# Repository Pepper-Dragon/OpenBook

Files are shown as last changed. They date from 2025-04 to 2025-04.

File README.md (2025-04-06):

# OpenBook
Proiect TSC - Diaconu Andrei 331CB

## Block Diagram

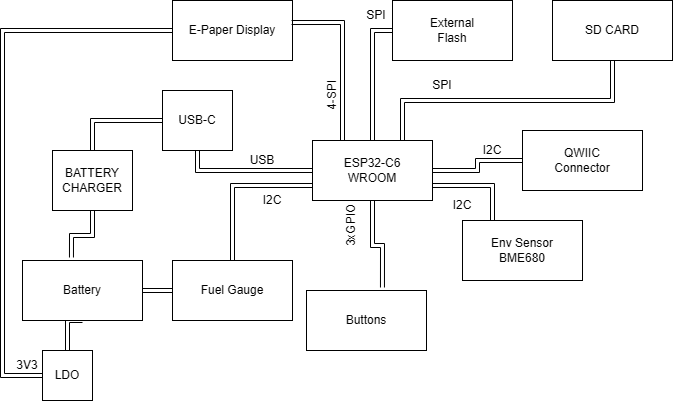
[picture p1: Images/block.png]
block


## Components

- **Microcontroller:** ESP32-C6 with integrated Wi-Fi 6 and Bluetooth 5 — responsible for core processing, communication, and power management.
- **Display:** 800×480 resolution e-Paper (e-Ink) display interfaced via SPI — ideal for low-power, high-visibility content rendering.
- **Sensors:** BME688 environmental sensor (temperature, humidity, pressure, air quality) connected through I2C.
- **Power Supply:** 2500mAh LiPo battery with USB-C charging and integrated fuel gauge for real-time battery monitoring.
- **Storage:** MicroSD card slot for storing e-books and other resources, communicating via SPI.
- **Real-Time Clock:** DS3231 RTC module with battery backup for accurate timekeeping even during power loss.
- **User Inputs:** 3 buttons (connected via GPIO) for navigation and control.
- **Expansion Options:** QWIIC/Stemma QT connector for easy integration of additional sensors or modules.

## Bill Of Materials

| name 	| value 	| description 	| quantity 	| link 	| datasheet 	|
|:---:	|:---:	|---	|:---:	|:---:	|---	|
| LED1 	| - 	| LED 	| 1 	| [link](https://www.niden.ro/led-uri-smd/4560-led-smd-0603-alb-rece.html) 	| [link](https://www.mouser.com/datasheet/2/423/LSM0603472V_(1)-1379786.pdf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)	|
| C18 	| 0.1uF/50V 	| CAPACITOR, European symbol 	| 1 	| [link](https://ro.mouser.com/ProductDetail/KEMET/C0402C104K4RAC7411?qs=GedzDrHbfJPMv36lRRfk4g%3D%3D) 	| [link](https://ro.mouser.com/datasheet/2/447/KEM_C1002_X7R_SMD-3316098.pdf) 	|
| R5 	| 0.47 	| RESISTOR, European symbol 	| 1 	| [link](https://ro.mouser.com/ProductDetail/ROHM-Semiconductor/SFR01MZPJ471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) 	| [link](https://fscdn.rohm.com/en/products/databook/datasheet/passive/resistor/chip_resistor/sfr-e.pdf) 	|
| R1 	| 100K 	| RESISTOR, European symbol 	| 1 	| [link](https://ro.mouser.com/ProductDetail/Bourns/CR0402-FX-1003GLF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) 	| [link](https://ro.mouser.com/datasheet/2/54/cr-1858361.pdf) 	|
| C1, C5, C21, C22, C23, C25, C26, C27 	| 100nF 	| CAPACITOR, European symbol 	| 8 	| [link](https://ro.mouser.com/ProductDetail/KEMET/C0402C104K4RAC7411?qs=GedzDrHbfJPMv36lRRfk4g%3D%3D) 	| [link](https://ro.mouser.com/datasheet/2/447/KEM_C1002_X7R_SMD-3316098.pdf) 	|
| C2 	| 100uF 	| POLARIZED CAPACITOR, European symbol 	| 1 	| [link](https://ro.mouser.com/ProductDetail/KEMET/T491B107M006AT?qs=U312oeP%2FpiHOgyk6KO2m0g%3D%3D) 	| [link](https://ro.mouser.com/datasheet/2/447/KEM_T2005_T491-3316937.pdf) 	|
| R18 	| 10K 	| RESISTOR, European symbol 	| 1 	| [link](https://ro.mouser.com/ProductDetail/Vishay-Dale/CRCW040210K0FKEDC?qs=E3Y5ESvWgWPiNLcGzwCGPg%3D%3D) 	| [link](https://www.vishay.com/docs/28773/crcwce3.pdf) 	|
| R6, R10, R11, R12, R13, R14, R15, R16, R19, R20, R21, R22, R23, R24, R25 	| 10k 	| RESISTOR, European symbol 	| 15 	| [link](https://ro.mouser.com/ProductDetail/Vishay-Dale/CRCW040210K0FKEDC?qs=E3Y5ESvWgWPiNLcGzwCGPg%3D%3D) 	| [link](https://www.vishay.com/docs/28773/crcwce3.pdf) 	|
| C7 	| 10uF 	| CAPACITOR, European symbol 	| 1 	| [link](https://ro.mouser.com/ProductDetail/KEMET/C0402C106M7PAC7867?qs=kZJHmUDErizJnkDIcqVWRQ%3D%3D) 	| [link](https://ro.mouser.com/datasheet/2/447/KEM_C1006_X5R_SMD-3316465.pdf) 	|
| J1 	| - 	| Micro SD Card Socket, Push-Push Type, Top Mount, SMT, H=1.83mm, 10u 	| 1 	| [link](https://www.digikey.ro/en/products/detail/attend-technology/112A-TAAR-R03/17633923) 	| [link](https://www.attend.com.tw/data/download/file/112A-TAAR-R03_Spec.pdf) 	|
| R17 	| 15 	| RESISTOR, European symbol 	| 1 	| [link](https://www.soselectronic.com/ro-ro/products/yageo/r0402-5-15-r-rc0402jr-0715rl-1-81614) 	| [link](https://cdn.soselectronic.com/productdata/4b/af/65353ac1/r0402-1-1-5-k-rc0402fr-071k5l-1.pdf) 	|
| C24 	| 1uF 	| CAPACITOR, European symbol 	| 1 	| [link](https://ro.mouser.com/ProductDetail/KEMET/C0402C105Z9VACTU?qs=gt1LBUVyoHlQieoJt4iw1w%3D%3D) 	| [link](https://ro.mouser.com/datasheet/2/447/KEM_C1005_Y5V_SMD-3316374.pdf) 	|
| C11, C12, C13, C14, C15, C16, C17, C19, C20 	| 1uF/50V 	| CAPACITOR, European symbol 	| 9 	| [link](https://ro.mouser.com/ProductDetail/KEMET/C0402C105Z9VACTU?qs=gt1LBUVyoHlQieoJt4iw1w%3D%3D) 	| [link](https://ro.mouser.com/datasheet/2/447/KEM_C1005_Y5V_SMD-3316374.pdf) 	|
| R7 	| 2.2 	| RESISTOR, European symbol 	| 1 	| [link](https://ro.mouser.com/ProductDetail/Panasonic/ERJ-PA2J2R2X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) 	| [link](https://industrial.panasonic.com/cdbs/www-data/pdf/RDO0000/AOA0000C331.pdf) 	|
| R8 	| 200 	| RESISTOR, European symbol 	| 1 	| [link](https://ro.mouser.com/ProductDetail/Vishay-Thin-Film/PNM0402E2000BSTS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) 	| [link](https://www.vishay.com/docs/60057/pnm.pdf) 	|
| Q1, Q3 	| 20V/4.2A/52mO/1.4W 	| P-channel MOSFETs 	| 2 	| [link](https://www.digikey.ro/en/products/detail/vishay-siliconix/SI1308EDL-T1-GE3/4876435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) 	| [link](https://www.vishay.com/docs/63399/si1308edl.pdf) 	|
| R9 	| 2k 	| RESISTOR, European symbol 	| 1 	| [link](https://ro.mouser.com/ProductDetail/Vishay-Dale/CRCW04022K00FKEE?qs=raETa%252B32nO8lGcRW9MjUBA%3D%3D) 	| [link](https://www.vishay.com/docs/20035/dcrcwe3.pdf) 	|
| C6, C9, C10 	| 4.7uF 	| CAPACITOR, European symbol 	| 3 	| [link](https://ro.mouser.com/ProductDetail/KEMET/C0402C475K8PACTU?qs=ulEaXIWI0c9ebKRT3r3htg%3D%3D) 	| [link](https://ro.mouser.com/datasheet/2/447/KEM_C1006_X5R_SMD-3316465.pdf) 	|
| C3, C4 	| 4.7uF 	| CAPACITOR, European symbol 	| 2 	| [link](https://ro.mouser.com/ProductDetail/KEMET/C0402C475K8PACTU?qs=ulEaXIWI0c9ebKRT3r3htg%3D%3D) 	| [link](https://ro.mouser.com/datasheet/2/447/KEM_C1006_X5R_SMD-3316465.pdf) 	|
| C8 	| 4.7uF/25V 	| CAPACITOR, European symbol 	| 1 	| [link](https://ro.mouser.com/ProductDetail/KEMET/C0402C475K8PACTU?qs=ulEaXIWI0c9ebKRT3r3htg%3D%3D) 	| [link](https://ro.mouser.com/ProductDetail/KEMET/C0402C475K8PACTU?qs=ulEaXIWI0c9ebKRT3r3htg%3D%3D) 	|
| D3 	| 4.7uF/25V 	| ON SEMICONDUCTOR - MBR0530 - DIODE, SCHOTTKY, 0.5A, 30V, SOD-123 	| 1 	| [link](https://www.snapeda.com/parts/MBR0530/Onsemi/view-part/?ref=eda) 	| [link](https://www.snapeda.com/parts/MBR0530/ON%20Semiconductor/datasheet/) 	|
| R3, R4 	| 5k1 	| RESISTOR, European symbol 	| 2 	| [link](https://www.gme.cz/v/1484336/yageo-r0402-5k1-006w-1-smd-rezistor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) 	| [link](https://img.gme.cz/files/eshop_data/eshop_data/7/984-017/dsh.984-017.1.pdf) 	|
| L1 	| 68uH 	| coil 	| 1 	| [link](https://ro.mouser.com/ProductDetail/Wurth-Elektronik/744043680?qs=PGXP4M47uW6VkZq%252BkzjrHA%3D%3D) 	| [link](https://www.we-online.com/components/products/datasheet/744043680.pdf) 	|
| IC2 	| - 	| Voltage Detector with Adjustable Delay 	| 1 	| [link](https://ro.mouser.com/ProductDetail/ROHM-Semiconductor/BD5229G-TR?qs=4kLU8WoGk0vvnhrrYwdszw%3D%3D) 	| [link](https://fscdn.rohm.com/en/products/databook/datasheet/ic/power/voltage_detector/bd52xxg-e.pdf) 	|
| BOOT_BUTTON, CHANGE_BUTTON, RESET_BUTTON 	| - 	| Button 	| 3 	| [link](https://ro.mouser.com/ProductDetail/CK/PTS841-GK-SMTR-LFS?qs=d0WKAl%252BL4KbAtAqJT9yhkg%3D%3D) 	| [link](https://www.ckswitches.com/media/2805/pts841.pdf) 	|
| C28 	| - 	| Cap 0.011F 3.3V 1210 Flat 	| 1 	| [link](https://www.snapeda.com/parts/CPH3225A/Seiko+Instruments/view-part/?ref=eda) 	| [link](https://www.snapeda.com/parts/CPH3225A/Seiko%20Instruments/datasheet/) 	|
| U5 	| - 	| Real Time Clock Serial 16-Pin SOIC W T/R 	| 1 	| [link](https://www.snapeda.com/parts/DS3231SN%23/Analog+Devices/view-part/?ref=eda) 	| [link](https://www.snapeda.com/parts/DS3231SN%23/Analog%20Devices/datasheet/) 	|
| U2 	| - 	| ESP32 	| 1 	| [link](https://www.snapeda.com/parts/ESP32-C6-WROOM-1-N8/Espressif+Systems/view-part/?ref=eda) 	| [link](https://www.snapeda.com/parts/ESP32-C6-WROOM-1-N8/Espressif%20Systems/datasheet/) 	|
| R2 	| - 	| VARISTOR 	| 1 	| [link](https://www.digikey.ro/en/products/detail/epcos-tdk-electronics/B72580T0110K062/15903564) 	| [link](https://www.tdk-electronics.tdk.com/inf/75/db/CTVS_14/Standard_series.pdf) 	|
| D1, D6 	| - 	| Schottky Barrier Rectifier Diode 	| 2 	| [link](https://eu.mouser.com/ProductDetail/KYOCERA-AVX/SD0805S020S1R0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) 	| [link](https://ro.mouser.com/datasheet/2/40/schottky-3165252.pdf) 	|
| U3 	| - 	| Integrated Environmental Unit 	| 1 	| [link](https://ro.mouser.com/ProductDetail/Bosch-Sensortec/BME680?qs=v271MhAjFHjo0yA%2FC4OnDQ%3D%3D) 	| [link](https://ro.mouser.com/datasheet/2/783/BST_BME680_DS001-1509608.pdf) 	|
| U1 	| - 	| MCP73831T Li-Ion, Li-Pol Controller 	| 1 	| [link](https://eu.mouser.com/ProductDetail/Microchip-Technology/MCP73831T-2ACI-OT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) 	| [link](https://ro.mouser.com/datasheet/2/268/MCP73831_Family_Data_Sheet_DS20001984H-3441711.pdf) 	|
| J3 	| - 	|  (0.50mm) Surface Mount, Right Angle 	| 1 	| [link](https://ro.mouser.com/ProductDetail/Hirose-Connector/FH34SRJ-24S-0.5SH99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.) 	| [link](https://ro.mouser.com/datasheet/2/185/FH34SRJ_24S_0_5SH_99__CL0580_1255_6_99_2DDrawing_0-1615044.pdf) 	|
| U4 	| - 	| 3µA 1-Cell/2-Cell Fuel Gauge with ModelGauge 	| 1 	| [link](https://www.snapeda.com/parts/MAX17048G+T10/Analog+Devices/view-part/?ref=eda) 	| [link](https://www.snapeda.com/parts/MAX17048G+T10/Analog%20Devices/datasheet/) 	|
| D4, D5 	| - 	| DIODE, SCHOTTKY, 0.5A, 30V, SOD-123 	| 2 	| [link](https://www.snapeda.com/parts/MBR0530/Onsemi/view-part/?ref=eda) 	| [link](https://www.snapeda.com/parts/MBR0530/ON%20Semiconductor/datasheet/) 	|
| D7, D8, D9, D10, D11, D12 	| - 	| Ipp Tvs Diode 	| 6 	| [link](https://www.snapeda.com/parts/PGB1010603MR/Littelfuse/view-part/?ref=eda) 	| [link](https://www.snapeda.com/parts/PGB1010603MR/Littelfuse%20Inc./datasheet/) 	|
| J4 	| - 	| SparkFun I2C Standard Qwiic Connector 	| 1 	| [link](https://www.sparkfun.com/qwiic-jst-connector-smd-4-pin-horizontal.html) 	| [link](https://cdn.sparkfun.com/assets/parts/1/2/2/8/9/Qwiic_Connector_Datasheet.pdf) 	|
| J2 	| - 	| CONN USB 2.0 TYPE-C R/A SMT 	| 1 	| [link](https://ro.mouser.com/ProductDetail/GCT/USB4110-GF-A?qs=KUoIvG%2F9IlYiZvIXQjyJeA%3D%3D) 	| [link](https://ro.mouser.com/datasheet/2/837/GCT_USB4110_Product_Drawing___20k_cycles-3455479.pdf) 	|
| Q2 	| - 	| MOSFET N-Ch 30V 1.5A 	| 1 	| [link](https://www.snapeda.com/parts/SI1308EDL-T1-GE3/Vishay+Siliconix/view-part/?ref=eda) 	| [link](https://www.snapeda.com/parts/SI1308EDL-T1-GE3/Vishay%20Siliconix/datasheet/) 	|
| D2 	| - 	| Low Cap. ESD Protection Auto SOT-23-6 	| 1 	| [link](https://www.snapeda.com/parts/USBLC6-2SC6Y/STMicroelectronics/view-part/?ref=eda) 	| [link](https://www.snapeda.com/parts/USBLC6-2SC6Y/STMicroelectronics/datasheet/) 	|
| U6 	| - 	| FLASH - NOR Memory IC 512Mb 	| 1 	| [link](https://www.snapeda.com/parts/W25Q512JVEIQ/Winbond+Electronics/view-part/?ref=eda) 	| [link](https://www.snapeda.com/parts/W25Q512JVEIQ/Winbond%20Electronics/datasheet/) 	|
| IC1 	| - 	| LDO Voltage Regulator 	| 1 	| [link](https://ro.mouser.com/ProductDetail/Torex-Semiconductor/XC6220A331MR-G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) 	| [link](https://ro.mouser.com/datasheet/2/760/xc6220-3371556.pdf) 	|

## ESP32-C6 Pins

| Connection | Pin | Description |
|---|---|---|
| **RESET** | EN | Reset button for initiating a reset sequence |
| **INT_RTC** | IO0 | Interrupt signal for the RTC |
| **32KHZ** | IO1 | Input for 32kHz clock signal |
| **MISO** | IO2 | Master In Slave Out for communication between the microcontroller, Flash, SD Card, and display |
| **EPD_BUSY** | IO3 | Signal indicating if the display is busy |
| **SS_SD** | IO4 | Chip select for the SD card |
| **EPD_DC** | IO5 | Display data/command control pin |
| **SCK** | IO6 | SPI clock for synchronizing data transfers |
| **MOSI** | IO7 | Master Out Slave In for data transmission between the microcontroller, Flash, SD card, and display |
| **3V3** | IO8 | 3.3V power supply |
| **IO/BOOT** | IO9 | Boot button to trigger boot process |
| **EPD_CS** | IO10 | Chip select for the display |
| **FLASH_CS** | IO11 | Chip select for the Flash memory |
| **USB_D-** | IO12 | USB data negative for communication |
| **USB_D+** | IO13 | USB data positive for communication |
| **IO/CHANGE** | IO15 | Button to trigger a change action |
| **TX (UART)** | TXD0 / GPIO16  | Serial transmitter for UART communication |
| **RX (UART)** | RXD0 / GPIO17  | Serial receiver for UART communication |
| **RTC_RST** | IO18 | External reset for the RTC module |
| **I2C_PW** | IO19 | Power control signal for I2C devices |
| **EPD_3V3_C** | IO20 | 3.3V power supply for the display |
| **SDA (I2C)** | IO21 | Data line for I2C communication (e.g., RTC, BME688, Battery Gauge) |
| **SCL (I2C)** | IO22 | Clock line for I2C synchronization |
| **EPD_RST** | IO23 | Reset signal for the display |
| **3V3** | 3V3 | 3.3V power line |
| **GND** | GND | Ground connection |

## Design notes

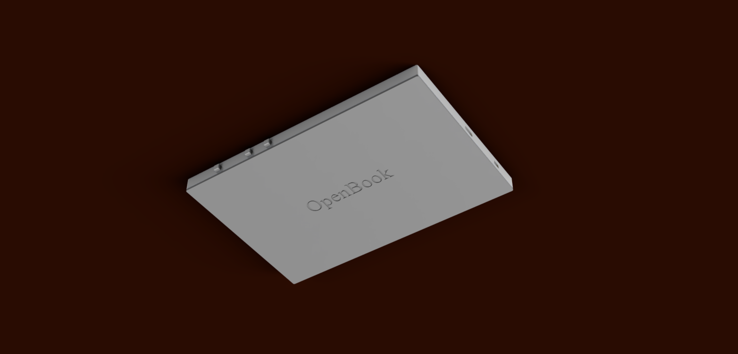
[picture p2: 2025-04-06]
Images/OpenBook_back.png

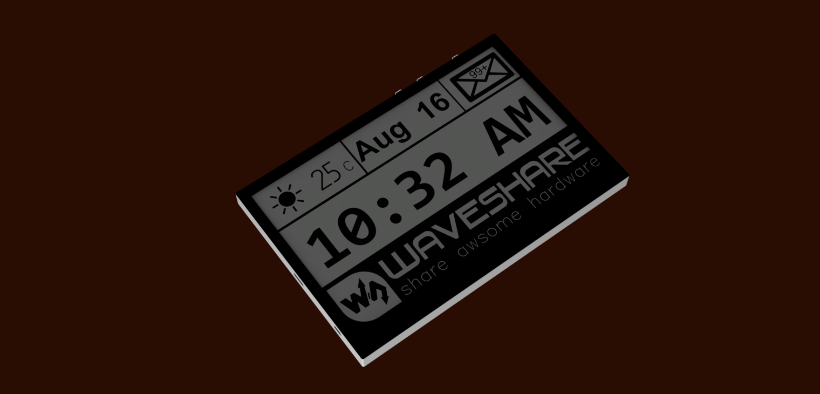
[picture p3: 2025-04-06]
Images/OpenBook_front.png

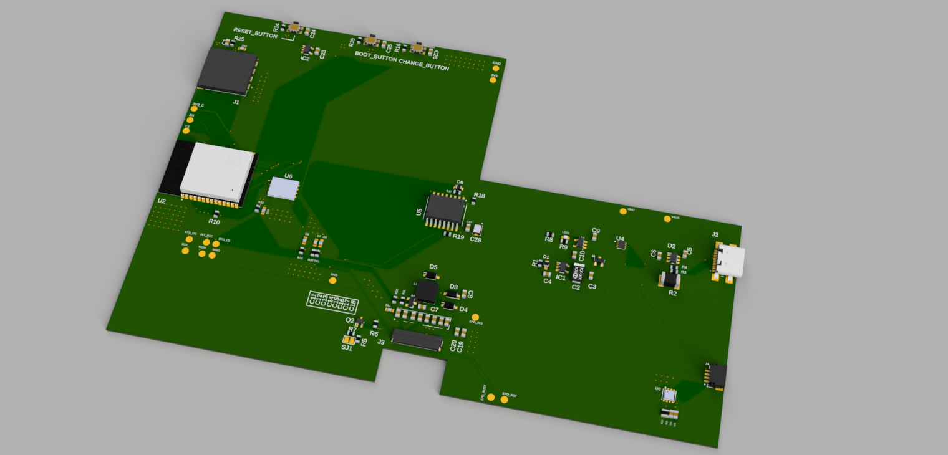
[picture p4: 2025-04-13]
Images/PCB.png

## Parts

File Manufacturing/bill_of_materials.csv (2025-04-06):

Qty | Value | Device | Package | Parts | Description | ARROW_PART_NUMBER | ARROW_PRICE-STOCK | AVAILABILITY | CENTROID_NOT_SPECIFIED | CHECK_PRICES | COPYRIGHT | DATASHEET | DESCRIPTION | DIGIKEY_DESCRIPTION | DIGIKEY_PART_NUMBER | HEIGHT | LEAD_FREE | MANUFACTURER_NAME | MANUFACTURER_PART_NUMBER | MF | MFR_NAME | MOUSER_PART_NUMBER | MOUSER_PRICE-STOCK | MOUSER_TESTING_PART_NUMBER | MOUSER_TESTING_PRICE-STOCK | MP | MPN | PACKAGE | POPULARITY | PREFIX | PRICE | PROD_ID | PURCHASE-URL | ROHS | SNAPEDA_LINK | SPICEMODEL | SPICEPREFIX | TEMPERATURE_RANGE_HIGH | TEMPERATURE_RANGE_LOW | TP_SIGNAL_NAME | VALUE
1 |  | ADAFRUIT_LEDCHIP-LED0603 | ADAFRUIT_CHIP-LED0603 | LED1 | LED
1 |  | SJ | SJ | SJ1 | SMD solder JUMPER |  |  |  |  |  |  |  |  |  |  |  |  |  |  |  |  |  |  |  |  |  |  |  | 3
1 | 0.1uF/50V | EAGLE-LTSPICE_CC0402 | EAGLE-LTSPICE_C0402 | C18 | CAPACITOR, European symbol |  |  |  |  |  |  |  |  |  |  |  |  |  |  |  |  |  |  |  |  |  |  |  |  |  |  |  |  |  |  | NONE | C
1 | 0.47 | ESP32_WROVER_EAGLE-LTSPICE_RR0402 | ESP32_WROVER_EAGLE-LTSPICE_R0402 | R5 | RESISTOR, European symbol |  |  |  |  |  |  |  |  |  |  |  |  |  |  |  |  |  |  |  |  |  |  |  |  |  |  |  |  |  |  | NONE | R
1 | 100K | ESP32_WROVER_EAGLE-LTSPICE_RR0402 | ESP32_WROVER_EAGLE-LTSPICE_R0402 | R1 | RESISTOR, European symbol |  |  |  |  |  |  |  |  |  |  |  |  |  |  |  |  |  |  |  |  |  |  |  |  |  |  |  |  |  |  | NONE | R
8 | 100nF | EAGLE-LTSPICE_CC0402 | EAGLE-LTSPICE_C0402 | C1, C5, C21, C22, C23, C25, C26, C27 | CAPACITOR, European symbol |  |  |  |  |  |  |  |  |  |  |  |  |  |  |  |  |  |  |  |  |  |  |  |  |  |  |  |  |  |  | NONE | C
1 | 100uF | RCL_CPOL-EUCT3528 | RCL_CT3528 | C2 | POLARIZED CAPACITOR, European symbol |  |  |  |  |  |  |  |  |  |  |  |  |  |  |  |  |  |  |  |  |  |  |  | 0 |  |  |  |  |  |  |  | C
1 | 10K | ESP32_WROVER_EAGLE-LTSPICE_RR0402 | ESP32_WROVER_EAGLE-LTSPICE_R0402 | R18 | RESISTOR, European symbol |  |  |  |  |  |  |  |  |  |  |  |  |  |  |  |  |  |  |  |  |  |  |  |  |  |  |  |  |  |  | NONE | R
15 | 10k | ESP32_WROVER_EAGLE-LTSPICE_RR0402 | ESP32_WROVER_EAGLE-LTSPICE_R0402 | R6, R10, R11, R12, R13, R14, R15, R16, R19, R20, R21, R22, R23, R24, R25 | RESISTOR, European symbol |  |  |  |  |  |  |  |  |  |  |  |  |  |  |  |  |  |  |  |  |  |  |  |  |  |  |  |  |  |  | NONE | R
1 | 10uF | EAGLE-LTSPICE_CC0402 | EAGLE-LTSPICE_C0402 | C7 | CAPACITOR, European symbol |  |  |  |  |  |  |  |  |  |  |  |  |  |  |  |  |  |  |  |  |  |  |  |  |  |  |  |  |  |  | NONE | C
1 | 112A-TAAR-R03_ATTEND | 112A-TAAR-R03_ATTEND | 112ATAARR03ATTEND | J1 | Micro SD Card Socket, Push-Push Type, Top Mount, SMT, H=1.83mm, 10u |  |  |  |  |  |  |  | Micro SD Card Socket | Push-Push Type | Top Mount | SMT | H=1.83mm | 10u |  |  | 1.9mm |  | ATTEND | 112A-TAAR-R03 ATTEND
1 | 15 | ESP32_WROVER_EAGLE-LTSPICE_RR0402 | ESP32_WROVER_EAGLE-LTSPICE_R0402 | R17 | RESISTOR, European symbol |  |  |  |  |  |  |  |  |  |  |  |  |  |  |  |  |  |  |  |  |  |  |  |  |  |  |  |  |  |  | NONE | R
1 | 1uF | EAGLE-LTSPICE_CC0402 | EAGLE-LTSPICE_C0402 | C24 | CAPACITOR, European symbol |  |  |  |  |  |  |  |  |  |  |  |  |  |  |  |  |  |  |  |  |  |  |  |  |  |  |  |  |  |  | NONE | C
9 | 1uF/50V | EAGLE-LTSPICE_CC0402 | EAGLE-LTSPICE_C0402 | C11, C12, C13, C14, C15, C16, C17, C19, C20 | CAPACITOR, European symbol |  |  |  |  |  |  |  |  |  |  |  |  |  |  |  |  |  |  |  |  |  |  |  |  |  |  |  |  |  |  | NONE | C
1 | 2.2 | ESP32_WROVER_EAGLE-LTSPICE_RR0402 | ESP32_WROVER_EAGLE-LTSPICE_R0402 | R7 | RESISTOR, European symbol |  |  |  |  |  |  |  |  |  |  |  |  |  |  |  |  |  |  |  |  |  |  |  |  |  |  |  |  |  |  | NONE | R
1 | 200 | ESP32_WROVER_EAGLE-LTSPICE_RR0402 | ESP32_WROVER_EAGLE-LTSPICE_R0402 | R8 | RESISTOR, European symbol |  |  |  |  |  |  |  |  |  |  |  |  |  |  |  |  |  |  |  |  |  |  |  |  |  |  |  |  |  |  | NONE | R
2 | 20V/4.2A/52mO/1.4W | ESP32_WROVER_SPARKFUN-DISCRETESEMI_MOSFET_PCH-DMG2305UX-7 | ESP32_WROVER_SPARKFUN-DISCRETESEMI_SOT23-3 | Q1, Q3 | P-channel MOSFETs |  |  |  |  |  |  |  |  |  |  |  |  |  |  |  |  |  |  |  |  |  |  |  |  |  |  | TRAN-14388 |  |  |  |  |  |  |  |  | 20V/4.2A/52mO/1.4W
1 | 2k | ESP32_WROVER_EAGLE-LTSPICE_RR0402 | ESP32_WROVER_EAGLE-LTSPICE_R0402 | R9 | RESISTOR, European symbol |  |  |  |  |  |  |  |  |  |  |  |  |  |  |  |  |  |  |  |  |  |  |  |  |  |  |  |  |  |  | NONE | R
3 | 4.7uF | EAGLE-LTSPICE_CC0402 | EAGLE-LTSPICE_C0402 | C6, C9, C10 | CAPACITOR, European symbol |  |  |  |  |  |  |  |  |  |  |  |  |  |  |  |  |  |  |  |  |  |  |  |  |  |  |  |  |  |  | NONE | C
2 | 4.7uF | ESP32_WROVER_EAGLE-LTSPICE_C | ESP32_WROVER_EAGLE-LTSPICE_C0402 | C3, C4 | CAPACITOR, European symbol
1 | 4.7uF/25V | EAGLE-LTSPICE_CC0402 | EAGLE-LTSPICE_C0402 | C8 | CAPACITOR, European symbol |  |  |  |  |  |  |  |  |  |  |  |  |  |  |  |  |  |  |  |  |  |  |  |  |  |  |  |  |  |  | NONE | C
1 | 4.7uF/25V | MBR0530 | SOD3716X135N | D3 | ON SEMICONDUCTOR - MBR0530 - DIODE, SCHOTTKY, 0.5A, 30V, SOD-123 |  |  | In Stock |  | https://www.snapeda.com/parts/MBR0530/Onsemi/view-part/?ref=eda |  |  | Diode Schottky 30 V 500mA Surface Mount SOD-123 |  |  |  |  |  |  | ON Semiconductor |  |  |  |  |  | MBR0530 |  | SOD-123-2 ON Semiconductor |  |  | None |  | https://www.snapeda.com/api/url_track_click_mouser/?unipart_id=179458&manufacturer=ON Semiconductor&part_name=MBR0530&search_term=None |  | https://www.snapeda.com/parts/MBR0530/Onsemi/view-part/?ref=snap
2 | 5k1 | ESP32_WROVER_EAGLE-LTSPICE_RR0402 | ESP32_WROVER_EAGLE-LTSPICE_R0402 | R3, R4 | RESISTOR, European symbol |  |  |  |  |  |  |  |  |  |  |  |  |  |  |  |  |  |  |  |  |  |  |  |  |  |  |  |  |  |  | NONE | R
1 | 68uH | 744043680IND_4828-WE-TPC_WRE | IND_4828-WE-TPC_WRE | L1 |  |  |  |  |  |  | Copyright (C) 2024 Ultra Librarian. All rights reserved. |  |  |  |  |  |  |  | 744043680 |  | Wurth Electronics
1 | BD5229G-TR | BD5229G-TR | SOT95P280X125-5N | IC2 | Voltage Detector with Adjustable Delay Time: CMOS processes are utilized to develop high precision, low current consumption CMOS reset ICs that allow arbitrary setting of the delay time. The extensive lineup includes both Nch Open Drain and CMOS output types in a wide range of detection voltages (from 2.3V to 6.0V, in 0.1V steps), enabling selection of the ideal solution based on customer requirements. In addition, the entire series is of course both lead-free and RoHS-compliant. |  |  |  |  |  |  |  | Voltage Detector with Adjustable Delay Time: CMOS processes are utilized to develop high precision | low current consumption CMOS reset ICs that allow arbitrary setting of the delay time. The extensive lineup includes both Nch Open Drain and CMOS output types in a wide range of detection voltages (from 2.3V to 6.0V | in 0.1V steps) | enabling selection of the ideal solution based on customer requirements. In addition | the entire series is of course both lead-free and RoHS-compliant. |  |  | 1.25mm |  | ROHM Semiconductor | BD5229G-TR |  |  | 755-BD5229G-TR | https://www.mouser.co.uk/ProductDetail/ROHM-Semiconductor/BD5229G-TR?qs=4kLU8WoGk0vvnhrrYwdszw%3D%3D
3 | BUTTON_CUSYOMV1 | BUTTON_CUSYOMV1 | MYBUTTON | BOOT_BUTTON, CHANGE_BUTTON, RESET_BUTTON
1 | CPH3225A | CPH3225A | CAPCP3225X100N | C28 | Cap 0.011F 3.3V 1210 Flat Check availability |  |  | Not in stock |  | https://www.snapeda.com/parts/CPH3225A/Seiko+Instruments/view-part/?ref=eda |  |  | 11 mF (EDLC) Supercapacitor 3.3 V 1210 (3225 Metric) - - |  |  |  |  |  |  | Seiko Instruments |  |  |  |  |  | CPH3225A |  | 1210 Seiko |  |  | None |  | https://www.snapeda.com/api/url_track_click_mouser/?unipart_id=562593&manufacturer=Seiko Instruments&part_name=CPH3225A&search_term=None |  | https://www.snapeda.com/parts/CPH3225A/Seiko+Instruments/view-part/?ref=snap
1 | DS3231SN# | DS3231SN# | SOIC127P1032X265-16N | U5 | Real Time Clock Serial 16-Pin SOIC W T/R Check availability |  |  | In Stock |  | https://www.snapeda.com/parts/DS3231SN%23/Analog+Devices/view-part/?ref=eda |  |  | Extremely Accurate I²C-Integrated RTC/TCXO/Crystal |  |  |  |  |  |  | Analog Devices |  |  |  |  |  | DS3231SN# |  | SOIC-16 Maxim |  |  | None |  | https://www.snapeda.com/api/url_track_click_mouser/?unipart_id=99048&manufacturer=Analog Devices&part_name=DS3231SN#&search_term=None |  | https://www.snapeda.com/parts/DS3231SN%23/Analog+Devices/view-part/?ref=snap
1 | ESP32-C6-WROOM-1-N8 | ESP32-C6-WROOM-1-N8 | XCVR_ESP32-C6-WROOM-1-N8 | U2 | Check availability |  |  | In Stock |  | https://www.snapeda.com/parts/ESP32-C6-WROOM-1-N8/Espressif+Systems/view-part/?ref=eda |  |  | Multiprotocol Modules ESP32-C6 module | Wi-Fi 6 in 2.4 GHz band | Bluetooth 5 | Zigbee 3.0 and Thread. ESP34-WROOM Compatible - ENGINEERING SAMPLE |  |  |  |  |  |  | Espressif Systems |  |  |  |  |  | ESP32-C6-WROOM-1-N8 |  | None |  |  | None |  |  |  | https://www.snapeda.com/parts/ESP32-C6-WROOM-1-N8/Espressif+Systems/view-part/?ref=snap
1 | ESP32C6_VARISTORCN1812 | ESP32C6_VARISTORCN1812 | ESP32C6_VARISTOR_CT/CN1812 | R2 | VARISTOR |  |  |  |  |  |  |  |  |  |  |  |  |  |  |  |  |  |  |  |  |  |  |  | 0
2 | ESP32_WROVER_AVX---SD0805S020S1R0_AVX_SD0805S020S1R0_0_0AVX_SD0805S020S1R0_0_0 | ESP32_WROVER_AVX---SD0805S020S1R0_AVX_SD0805S020S1R0_0_0AVX_SD0805S020S1R0_0_0 | ESP32_WROVER_AVX---SD0805S020S1R0_AVX_SD0805S020S1R0_0 | D1, D6 | Schottky Barrier Rectifier Diode |  |  |  | No |  |  | http://datasheets.avx.com/schottky.pdf |  | DIODE SCHOTTKY 20V 1A 0805 | 478-7800-1-ND |  | yes |  |  | AVX |  | 581-SD0805S020S1R0 |  |  |  |  |  | 0805 (2012 metric) |  | D |  |  |  | yes |  |  |  | +125°C | -55°C
1 | ESP32_WROVER_BME680_BME680 | ESP32_WROVER_BME680_BME680 | ESP32_WROVER_BME680_PSON80P300X300X100-8N | U3 | Integrated Environmental Unit |  |  | Unavailable |  |  |  |  | Integrated Environmental Unit |  |  |  |  |  |  | Bosch Sensortec |  |  |  |  |  | BME680 |  | LGA-8 Bosch Tools |  |  | None
1 | ESP32_WROVER_SPARKFUN-IC-POWER_MCP73831 | ESP32_WROVER_SPARKFUN-IC-POWER_MCP73831 | ESP32_WROVER_SPARKFUN-IC-POWER_SOT23-5 | U1 | MCP73831T Li-Ion, Li-Pol Controller |  |  |  |  |  |  |  |  |  |  |  |  |  |  |  |  |  |  |  |  |  |  |  |  |  |  | IC-09995
1 | FH34SRJ-24S-0.5SH_99_ | FH34SRJ-24S-0.5SH_99_ | FH34SRJ24S05SH99 | J3 | (0.50mm) Surface Mount, Right Angle |  |  |  |  |  |  |  | 24 Position FFC | FPC Connector Contacts | (0.50mm) Surface Mount | Right Angle |  |  | 1.1mm |  | Hirose | FH34SRJ-24S-0.5SH(99) |  |  | 798-FH34SRJ24S05SH99 | https://www.mouser.co.uk/ProductDetail/Hirose-Connector/FH34SRJ-24S-0.5SH99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
1 | MAX17048G+T10 | MAX17048G+T10 | SON50P200X200X80-9N | U4 | Check availability |  |  | In Stock |  | https://www.snapeda.com/parts/MAX17048G+T10/Analog+Devices/view-part/?ref=eda |  |  | 3µA 1-Cell/2-Cell Fuel Gauge with ModelGauge |  |  |  |  |  |  | Analog Devices |  |  |  |  |  | MAX17048G+T10 |  | TDFN-8 Maxim |  |  | None |  | https://www.snapeda.com/api/url_track_click_mouser/?unipart_id=329239&manufacturer=Analog Devices&part_name=MAX17048G+T10&search_term=None |  | https://www.snapeda.com/parts/MAX17048G+T10/Analog+Devices/view-part/?ref=snap
2 | MBR0530 | MBR0530 | SOD3716X135N | D4, D5 | ON SEMICONDUCTOR - MBR0530 - DIODE, SCHOTTKY, 0.5A, 30V, SOD-123 |  |  | In Stock |  | https://www.snapeda.com/parts/MBR0530/Onsemi/view-part/?ref=eda |  |  | Diode Schottky 30 V 500mA Surface Mount SOD-123 |  |  |  |  |  |  | ON Semiconductor |  |  |  |  |  | MBR0530 |  | SOD-123-2 ON Semiconductor |  |  | None |  | https://www.snapeda.com/api/url_track_click_mouser/?unipart_id=179458&manufacturer=ON Semiconductor&part_name=MBR0530&search_term=None |  | https://www.snapeda.com/parts/MBR0530/Onsemi/view-part/?ref=snap
6 | PGB1010603MR | PGB1010603MR | DIOC1608X36N | D7, D8, D9, D10, D11, D12 | Check availability |  |  | In Stock |  | https://www.snapeda.com/parts/PGB1010603MR/Littelfuse/view-part/?ref=eda |  |  | 150V (Typ) Clamp - Ipp Tvs Diode Surface Mount 0603 (1608 Metric) |  |  |  |  |  |  | Littelfuse Inc. |  |  |  |  |  | PGB1010603MR |  | 0603 Littelfuse Inc. |  |  | None |  | https://www.snapeda.com/api/url_track_click_mouser/?unipart_id=5659453&manufacturer=Littelfuse Inc.&part_name=PGB1010603MR&search_term=None |  | https://www.snapeda.com/parts/PGB1010603MR/Littelfuse/view-part/?ref=snap
1 | QWIIC_RIGHT_ANGLE | QWIIC_CONNECTORJS-1MM | JST04_1MM_RA | J4 | SparkFun I2C Standard Qwiic Connector |  |  |  |  |  |  |  |  |  |  |  |  |  |  |  |  |  |  |  |  |  |  |  |  |  |  | CONN-13694 |  |  |  |  |  |  |  |  | QWIIC_RIGHT_ANGLE
1 | SAMACSYS_PARTS_USB4110-GF-A | SAMACSYS_PARTS_USB4110-GF-A | SAMACSYS_PARTS_USB4110GFA | J2 | CONN USB 2.0 TYPE-C R/A SMT |  |  |  |  |  |  |  | CONN USB 2.0 TYPE-C R/A SMT |  |  | 3.26mm |  | GCT (GLOBAL CONNECTOR TECHNOLOGY) | USB4110-GF-A |  |  | 640-USB4110-GF-A | https://www.mouser.co.uk/ProductDetail/GCT/USB4110-GF-A?qs=KUoIvG%2F9IlYiZvIXQjyJeA%3D%3D
1 | SI1308EDL-T1-GE3 | SI1308EDL-T1-GE3 | SOT65P210X110-3N | Q2 | MOSFET N-Ch 30V 1.5A TrenchFET SC70 Vishay Si1308EDL-T1-GE3 N-channel MOSFET Transistor, 1.5 A, 30 V, 3-Pin SC-70 |  |  | In Stock |  | https://www.snapeda.com/parts/SI1308EDL-T1-GE3/Vishay+Siliconix/view-part/?ref=eda |  |  | Si1308EDL-T1-GE3 N-channel MOSFET Transistor | 1.5 A | 30 V | 3-Pin SC-70 | Siliconix / Vishay SI1308EDL-T1-GE3 |  |  |  |  |  |  | Vishay Siliconix |  |  |  |  |  | SI1308EDL-T1-GE3 |  | SOT-323 Vishay Semiconductor |  |  | None |  | https://www.snapeda.com/api/url_track_click_mouser/?unipart_id=274603&manufacturer=Vishay Siliconix&part_name=SI1308EDL-T1-GE3&search_term=None |  | https://www.snapeda.com/parts/SI1308EDL-T1-GE3/Vishay+Siliconix/view-part/?ref=snap
17 | TPTP20R | TPTP20R | TP20R | TP1, TP2, TP3, TP4, TP5, TP6, TP7, TP8, TP9, TP10, TP11, TP12, TP13, TP14, TP15, TP16, TP17 | Test pad |  |  |  |  |  |  |  |  |  |  |  |  |  |  |  |  |  |  |  |  |  |  |  | 2
1 | USBLC6-2SC6Y | USBLC6-2SC6Y | SOT95P280X145-6N | D2 | Low Cap. ESD Protection Auto SOT-23-6 STMicroelectronics USBLC6-2SC6Y, Dual Uni-Directional TVS Diode Array, 6-Pin SOT-23 |  |  | In Stock |  | https://www.snapeda.com/parts/USBLC6-2SC6Y/STMicroelectronics/view-part/?ref=eda |  |  | 17V Clamp 5A (8/20µs) Ipp Tvs Diode Surface Mount SOT-23-6 |  |  |  |  |  |  | STMicroelectronics |  |  |  |  |  | USBLC6-2SC6Y |  | SOT-23-6 STMicroelectronics |  |  | None |  |  |  | https://www.snapeda.com/parts/USBLC6-2SC6Y/STMicroelectronics/view-part/?ref=snap
1 | W25Q512JVEIQ | W25Q512JVEIQ | SON127P600X800X80-9N | U6 | Check availability |  |  | In Stock |  | https://www.snapeda.com/parts/W25Q512JVEIQ/Winbond+Electronics/view-part/?ref=eda |  |  | FLASH - NOR Memory IC 512Mb (64M x 8) SPI - Quad I/O 133 MHz 8-WSON (8x6) |  |  |  |  |  |  | Winbond Electronics |  |  |  |  |  | W25Q512JVEIQ |  | Package |  |  | None |  |  |  | https://www.snapeda.com/parts/W25Q512JVEIQ/Winbond+Electronics/view-part/?ref=snap
1 | XC6220A331MR-G | XC6220A331MR-G | SOT95P280X120-5N | IC1 | LDO Voltage Regulators |  |  |  |  |  |  |  | LDO Voltage Regulators |  |  | 1.2mm |  | Torex | XC6220A331MR-G |  |  | 865-XC6220A331MR-G | https://www.mouser.co.uk/ProductDetail/Torex-Semiconductor/XC6220A331MR-G?qs=AsjdqWjXhJ8ZSWznL1J0gg%3D%3D

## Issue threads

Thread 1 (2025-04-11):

Unrouted Airwires

robert-ercean, 2025-04-11:
## 🧰 **Issue:** Unrouted Airwires

There are unrouted airwires present in the PCB layout (2D Model).

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

## ✅ Quick Fix
Just run the **autorouter** again to complete the routing. **After that**, proceed to fix the other issues related to the GND plane.

Pepper-Dragon, 2025-04-11:
I looked into it, the .brd file exported withought via stitching for some reason.

robert-ercean, 2025-04-11:
Great! Seems like Fusion also reseted all my previously set preferences once i opened your board so the issue might have even been from me, gotta love working in Fusion 🥇

Pepper-Dragon, 2025-04-11:
I exported the board in a different format, I hope it solved the issue.

Closed 2025-04-13.

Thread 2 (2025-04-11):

GND Holes on Top and Bottom Layer

robert-ercean, 2025-04-11:
# 🧰 GND Holes on Top and Bottom Layer

There are empty spots on both the top and bottom layers' of the PCB which should be connected to the GND.

###  Affected Areas:
- GND holes on **Top Layer**
- GND holes on **Bottom Layer**

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

## ✅ Solution
Add **viases** that connect to GND plane and Fusion will automatically pour the GND planes in the empty spots.

Pepper-Dragon, 2025-04-11:
If you are talking about there being vias that don't have a route, vias can connect ground planes just by specifying that they are GND.

robert-ercean, 2025-04-11:
Good point, but I wasn't necessarily meaning that. There are empty spots on the top and bottom layer of the PCB in which there should be a GND pour, fixed the initial wording of the issue, hope it is more clear now, thanks :)

Pepper-Dragon, 2025-04-13:
I re-filled the polygon GND pours.

Closed 2025-04-13.

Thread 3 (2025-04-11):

Silkscreen overlap

robert-ercean, 2025-04-11:
# 🧰 Silkscreen Text Overlaps with Routes

The following components have silkscreen names that overlap with traces, which is not recommended:

- R8, C12, C13, C15, C17
- R4, R3
- BOOT_BUTTON, RESET_BUTTON

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

Pepper-Dragon, 2025-04-13:
I changed the silkscreen for those components.

Closed 2025-04-13.

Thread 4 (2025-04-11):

Board thickness

robert-ercean, 2025-04-11:
# Board Thickness is wrong

The current board thickness is set to **1.6mm**, but the requirement is **1mm**.

## ✅ Solution
Should just change fusion's default board thickness as below and then update the 3D Design by pressing *S* and typing *update*

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

Closed 2025-04-13.

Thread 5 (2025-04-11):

Outlines misalignment

robert-ercean, 2025-04-11:
## 🧰 Issue

Some parts of the board's outline are slightly misaligned or not straight.

## ✅ Solution
Should redimension the outline to ensure all sides are straight and aligned, I recommend just changing the coordinates of the affected outlines for a **quick fix**:

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

Pepper-Dragon, 2025-04-13:
I changed the coordonates.

Closed 2025-04-13.

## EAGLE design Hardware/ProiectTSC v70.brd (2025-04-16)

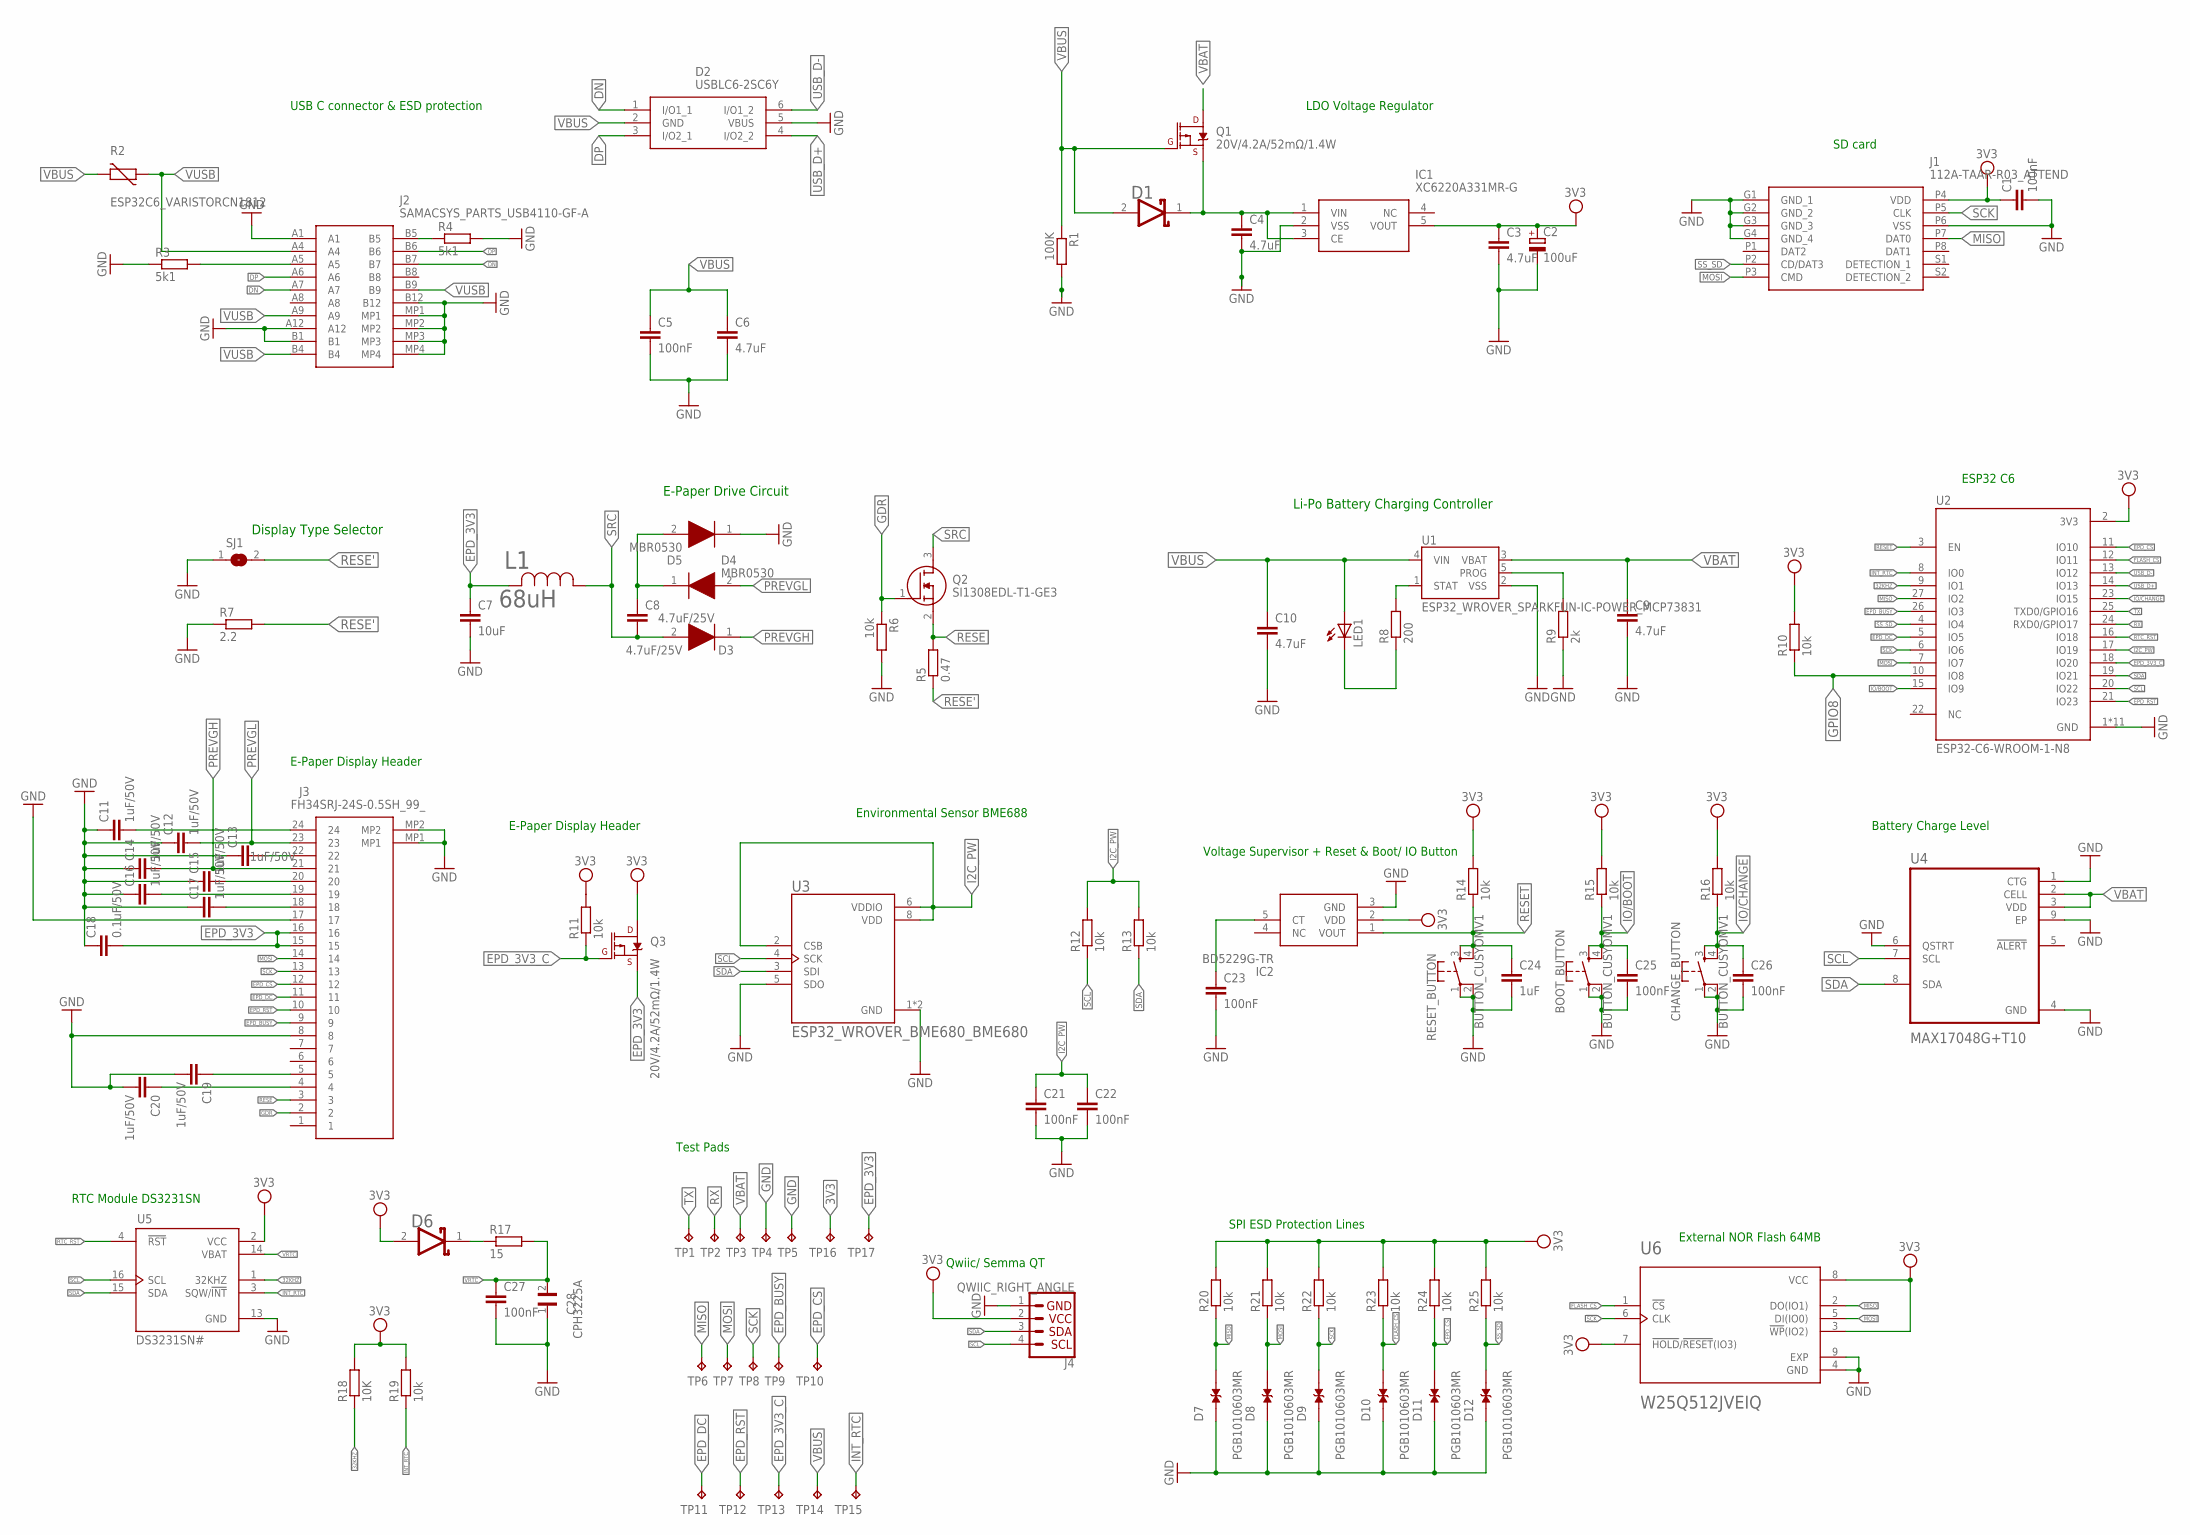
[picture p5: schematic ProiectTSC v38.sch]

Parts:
BOOT_BUTTON: BUTTON_CUSYOMV1; MYBUTTON
C1, C5, C21, C22, C23, C25, C26, C27: 100nF; EAGLE-LTSPICE_C0402
C2: 100uF; RCL_CT3528
C3, C4: 4.7uF; ESP32_WROVER_EAGLE-LTSPICE_C0402
C6, C9, C10: 4.7uF; EAGLE-LTSPICE_C0402
C7: 10uF; EAGLE-LTSPICE_C0402
C8: 4.7uF/25V; EAGLE-LTSPICE_C0402
C11, C12, C13, C14, C15, C16, C17, C19, C20: 1uF/50V; EAGLE-LTSPICE_C0402
C18: 0.1uF/50V; EAGLE-LTSPICE_C0402
C24: 1uF; EAGLE-LTSPICE_C0402
C28: CPH3225A; CAPCP3225X100N
CHANGE_BUTTON: BUTTON_CUSYOMV1; MYBUTTON
D1, D6: ESP32_WROVER_AVX---SD0805S020S1R0_AVX_SD0805S020S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; ESP32_WROVER_AVX---SD0805S020S1R0_AVX_SD0805S020S1R0_0
D2: USBLC6-2SC6Y; SOT95P280X145-6N
D3: 4.7uF/25V; SOD3716X135N
D4, D5: MBR0530; SOD3716X135N
D7, D8, D9, D10, D11, D12: PGB1010603MR; DIOC1608X36N
IC1: XC6220A331MR-G; SOT95P280X120-5N
IC2: BD5229G-TR; SOT95P280X125-5N
J1: 112A-TAAR-R03_ATTEND; 112ATAARR03ATTEND
J2: SAMACSYS_PARTS_USB4110-GF-A; SAMACSYS_PARTS_USB4110GFA
J3: FH34SRJ-24S-0.5SH_99_; FH34SRJ24S05SH99
J4: QWIIC_RIGHT_ANGLE; JST04_1MM_RA
L1: 68uH; IND_4828-WE-TPC_WRE
LED1: ADAFRUIT_LEDCHIP-LED0603; ADAFRUIT_CHIP-LED0603
Q1, Q3: 20V/4.2A/52mΩ/1.4W; ESP32_WROVER_SPARKFUN-DISCRETESEMI_SOT23-3
Q2: SI1308EDL-T1-GE3; SOT65P210X110-3N
R1: 100K; ESP32_WROVER_EAGLE-LTSPICE_R0402
R2: ESP32C6_VARISTORCN1812; ESP32C6_VARISTOR_CT/CN1812
R3, R4: 5k1; ESP32_WROVER_EAGLE-LTSPICE_R0402
R5: 0.47; ESP32_WROVER_EAGLE-LTSPICE_R0402
R6, R10, R11, R12, R13, R14, R15, R16, R19, R20, R21, R22, R23, R24, R25: 10k; ESP32_WROVER_EAGLE-LTSPICE_R0402
R7: 2.2; ESP32_WROVER_EAGLE-LTSPICE_R0402
R8: 200; ESP32_WROVER_EAGLE-LTSPICE_R0402
R9: 2k; ESP32_WROVER_EAGLE-LTSPICE_R0402
R17: 15; ESP32_WROVER_EAGLE-LTSPICE_R0402
R18: 10K; ESP32_WROVER_EAGLE-LTSPICE_R0402
RESET_BUTTON: BUTTON_CUSYOMV1; MYBUTTON
SJ1: SJ
TP1, TP2, TP3, TP4, TP5, TP6, TP7, TP8, TP9, TP10, TP11, TP12, TP13, TP14, TP15, TP16, TP17: TPTP20R; TP20R
U1: ESP32_WROVER_SPARKFUN-IC-POWER_MCP73831; ESP32_WROVER_SPARKFUN-IC-POWER_SOT23-5
U2: ESP32-C6-WROOM-1-N8; XCVR_ESP32-C6-WROOM-1-N8
U3: ESP32_WROVER_BME680_BME680; ESP32_WROVER_BME680_PSON80P300X300X100-8N
U4: MAX17048G+T10; SON50P200X200X80-9N
U5: DS3231SN#; SOIC127P1032X265-16N
U6: W25Q512JVEIQ; SON127P600X800X80-9N

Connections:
3V3: C1.1, C2.+, C3.1, D6.2 (ANODE), IC1.5 (VOUT), IC2.2 (VDD), J1.P4 (VDD), J4.2, Q3.3 (D), R10.2, R11.2, R14.2, R15.2, R16.2, R18.2, R19.2, R20.2, R21.2, R22.2, R23.2, R24.2, R25.2, TP16.TP, U2.2 (3V3), U5.2 (VCC), U6.3 (!WP!(IO2)), U6.7 (!HOLD!/!RESET!(IO3)), U6.8 (VCC)
32KHZ: R18.1, U2.9 (IO1), U5.1 (32KHZ)
DN: D2.1 (I/O1_1), J2.A7, J2.B7
DP: D2.3 (I/O2_1), J2.A6, J2.B6
EPD_3V3: C7.1, C18.2, J3.15, J3.16, L1.2, Q3.2 (S), TP17.TP
EPD_3V3_C: Q3.1 (G), R11.1, TP13.TP, U2.18 (IO20)
EPD_BUSY: J3.9, TP9.TP, U2.26 (IO3)
EPD_CS: D11.2, J3.12, R24.1, TP10.TP, U2.11 (IO10)
EPD_DC: J3.11, TP11.TP, U2.5 (IO5)
EPD_RST: J3.10, TP12.TP, U2.21 (IO23)
FLASH_CS: D10.2, R23.1, U2.12 (IO11), U6.1 (!CS)
GDR: J3.2, Q2.1 (G), R6.1
GND: BOOT_BUTTON.1, BOOT_BUTTON.2, C1.2, C2.-, C3.2, C4.2, C5.2, C6.2, C7.2, C9.2, C10.2, C11.1, C12.1, C13.1, C14.1, C15.1, C16.1, C17.1, C18.1, C19.2, C20.2, C21.2, C22.2, C23.2, C24.2, C25.2, C26.2, C27.2, C28.1, CHANGE_BUTTON.1, CHANGE_BUTTON.2, D2.5 (VBUS), D5.1 (K), D7.1, D8.1, D9.1, D10.1, D11.1, D12.1, IC1.2 (VSS), IC2.3 (GND), J1.G1 (GND_1), J1.G2 (GND_2), J1.G3 (GND_3), J1.G4 (GND_4), J1.P6 (VSS), J2.A1, J2.A12, J2.B1, J2.B12, J2.MP1, J2.MP2, J2.MP3, J2.MP4, J3.8, J3.17, J3.MP1, J3.MP2, J4.1, R1.2, R3.1, R4.2, R6.2, R7.1, R9.1, RESET_BUTTON.1, RESET_BUTTON.2, SJ1.1, TP4.TP, TP5.TP, U1.2 (VSS), U2.1 (GND), U2.28 (GND), U2.29_1 (GND), U2.29_2 (GND), U2.29_3 (GND), U2.29_4 (GND), U2.29_5 (GND), U2.29_6 (GND), U2.29_7 (GND), U2.29_8 (GND), U2.29_9 (GND), U3.1 (GND), U3.5 (SDO), U3.7 (GND), U4.1 (CTG), U4.4 (GND), U4.6 (QSTRT), U4.9 (EP), U5.13 (GND), U6.4 (GND), U6.9 (EXP)
GPIO8: R10.1, U2.10 (IO8)
I2C_PW: C21.1, C22.1, R12.2, R13.2, U2.17 (IO19), U3.2 (CSB), U3.6 (VDDIO), U3.8 (VDD)
INT_RTC: R19.1, TP15.TP, U2.8 (IO0), U5.3 (SQW/!INT)
IO/BOOT: BOOT_BUTTON.3, BOOT_BUTTON.4, C25.1, R15.1, U2.15 (IO9)
IO/CHANGE: C26.1, CHANGE_BUTTON.3, CHANGE_BUTTON.4, R16.1, U2.23 (IO15)
MISO: D7.2, J1.P7 (DAT0), R20.1, TP6.TP, U2.27 (IO2), U6.2 (DO(IO1))
MOSI: D8.2, J1.P3 (CMD), J3.14, R21.1, TP7.TP, U2.7 (IO7), U6.5 (DI(IO0))
unnamed: J2.B5, R4.1
unnamed: C11.2, J3.24
unnamed: C8.1, D4.1 (K), D5.2 (A)
unnamed: J2.A5, R3.2
unnamed: C19.1, J3.5
unnamed: C4.1, D1.1 (CATHODE), IC1.1 (VIN), IC1.3 (CE), Q1.2 (S)
unnamed: R9.2, U1.5 (PROG)
unnamed: C23.1, IC2.5 (CT)
unnamed: C20.1, J3.4
unnamed: C13.2, J3.22
unnamed: R8.2, U1.1 (STAT)
unnamed: LED1.C, R8.1
unnamed: D6.1 (CATHODE), R17.1
unnamed: C15.2, J3.20
unnamed: C16.2, J3.19
unnamed: C17.2, J3.18
PREVGH: C14.2, D3.1 (K), J3.21
PREVGL: C12.2, D4.2 (A), J3.23
RESE: J3.3, Q2.2 (S), R5.2
RESE': R5.1, R7.2, SJ1.2
RESET: C24.1, IC2.1 (VOUT), R14.1, RESET_BUTTON.3, RESET_BUTTON.4, U2.3 (EN)
RTC_RST: U2.16 (IO18), U5.4 (!RST)
RX: TP2.TP, U2.24 (RXD0/GPIO17)
SCK: D9.2, J1.P5 (CLK), J3.13, R22.1, TP8.TP, U2.6 (IO6), U6.6 (CLK)
SCL: J4.4, R12.1, U2.20 (IO22), U3.4 (SCK), U4.7 (SCL), U5.16 (SCL)
SDA: J4.3, R13.1, U2.19 (IO21), U3.3 (SDI), U4.8 (SDA), U5.15 (SDA)
SRC: C8.2, D3.2 (A), L1.1, Q2.3 (D)
SS_SD: D12.2, J1.P2 (CD/DAT3), R25.1, U2.4 (IO4)
TX: TP1.TP, U2.25 (TXD0/GPIO16)
USB_D+: D2.4 (I/O2_2), U2.14 (IO13)
USB_D-: D2.6 (I/O1_2), U2.13 (IO12)
VBAT: C9.1, Q1.3 (D), TP3.TP, U1.3 (VBAT), U4.2 (CELL), U4.3 (VDD)
VBUS: C5.1, C6.1, C10.1, D1.2 (ANODE), D2.2 (GND), LED1.A, Q1.1 (G), R1.1, R2.2, TP14.TP, U1.4 (VIN)
VRTC: C27.1, C28.2, R17.2, U5.14 (VBAT)
VUSB: J2.A4, J2.A9, J2.B4, J2.B9, R2.1

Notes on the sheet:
SD card
LDO Voltage Regulator
USB C connector & ESD protection
E-Paper Drive Circuit
Display Type Selector
Li-Po Battery Charging Controller
ESP32 C6
E-Paper Display Header
Environmental Sensor BME688
Voltage Supervisor + Reset & Boot/ IO Button
Battery Charge Level
RTC Module DS3231SN
Test Pads
Qwiic/ Semma QT
SPI ESD Protection Lines
External NOR Flash 64MB

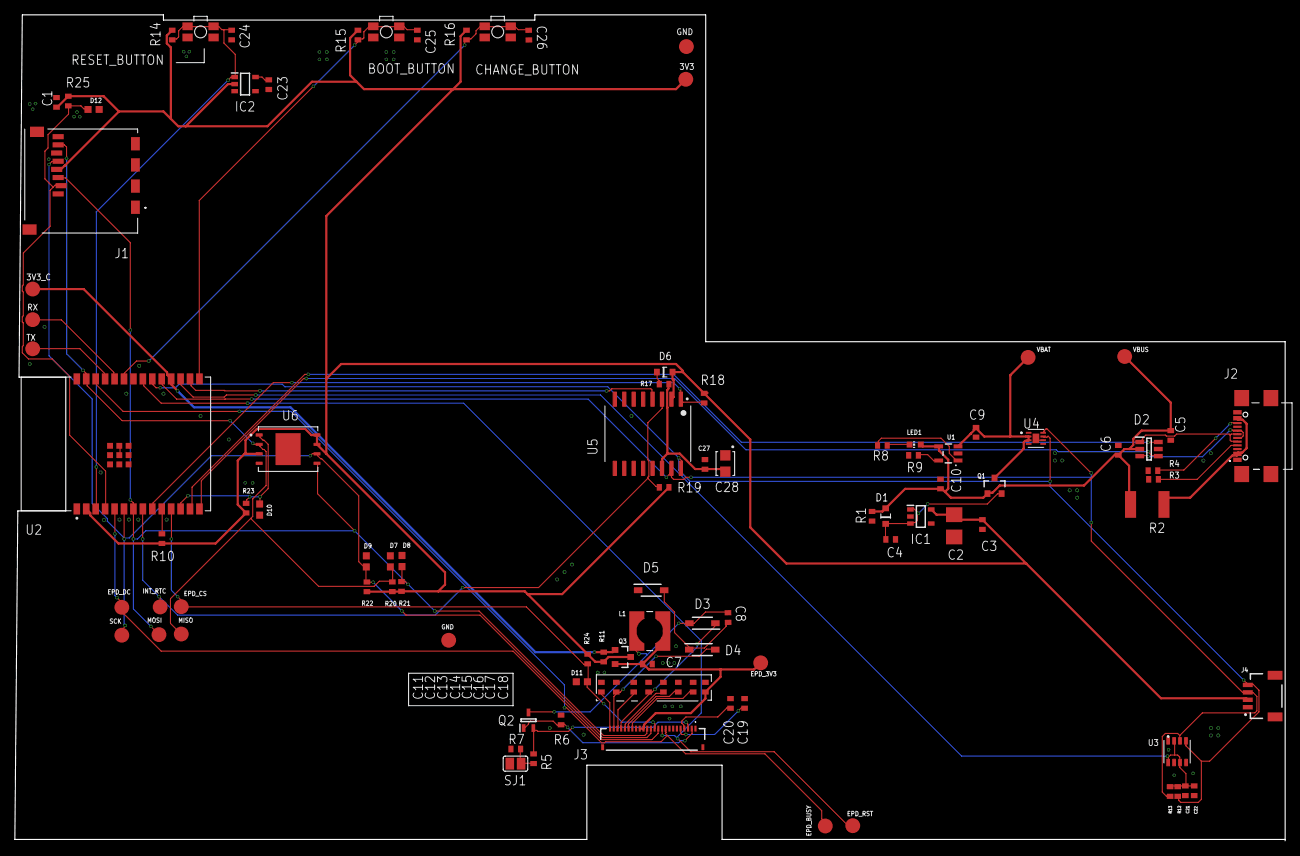
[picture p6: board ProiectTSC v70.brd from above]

Board: 2 copper layers, 171.0 x 111.0 mm, 103 parts (0 on the bottom side), 55 nets.

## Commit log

2025-04-11 added .fbrd board file because in .brd file via stitching disappeared
    [ProiectTSC_v64.brd]
2025-04-13 fixed review issues
    [ProiectTSC_v64.brd, ProiectTSC_v67.brd]
2025-04-16 last minute fix
    [ProiectTSC v70.brd, ProiectTSC_v67.brd]

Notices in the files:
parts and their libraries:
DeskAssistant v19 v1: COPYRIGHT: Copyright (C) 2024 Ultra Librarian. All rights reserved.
